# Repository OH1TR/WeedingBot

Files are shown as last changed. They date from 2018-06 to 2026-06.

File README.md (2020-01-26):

# This is collection of bits and pieces to build weeding bot. (or something)

Bot is build on frame of old lawn mover. Jetson Nano board handles communication with windows client. There is ZED-camera on board for images. Some custom PCB:s and China boards to contol motors.

Code is a mess, but it moves.. :-)

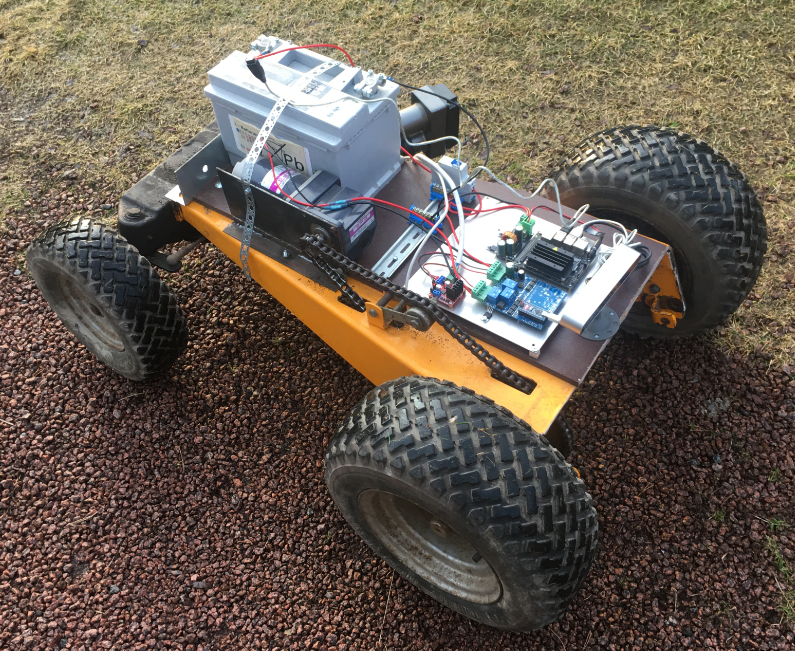
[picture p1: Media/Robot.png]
Robot


Video: https://www.facebook.com/100010379521880/videos/999905427032099/

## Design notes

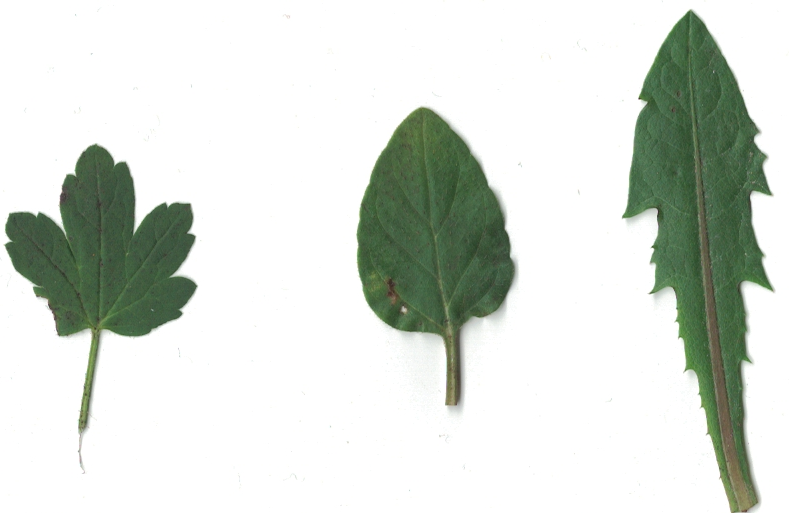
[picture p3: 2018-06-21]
RandomStuff/PlantDetect/Scanned.png

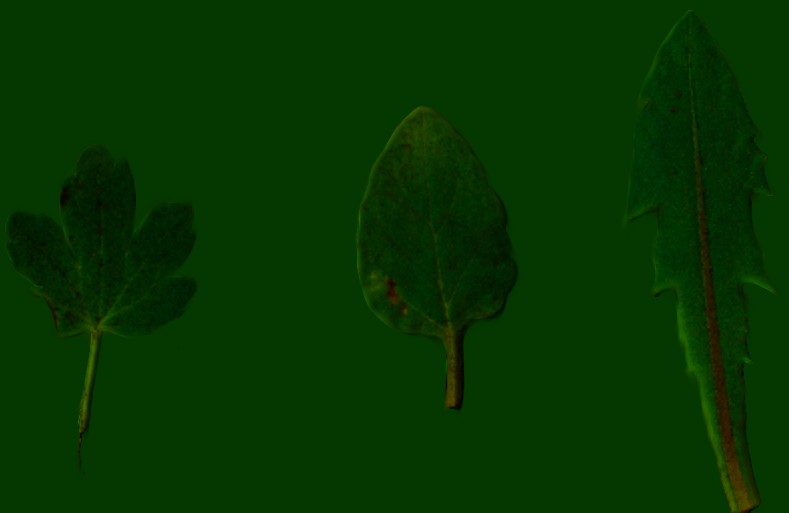
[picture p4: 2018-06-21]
RandomStuff/PlantDetect/Scanned2.png

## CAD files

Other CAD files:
RandomStuff/PlantDetect/pla.blend

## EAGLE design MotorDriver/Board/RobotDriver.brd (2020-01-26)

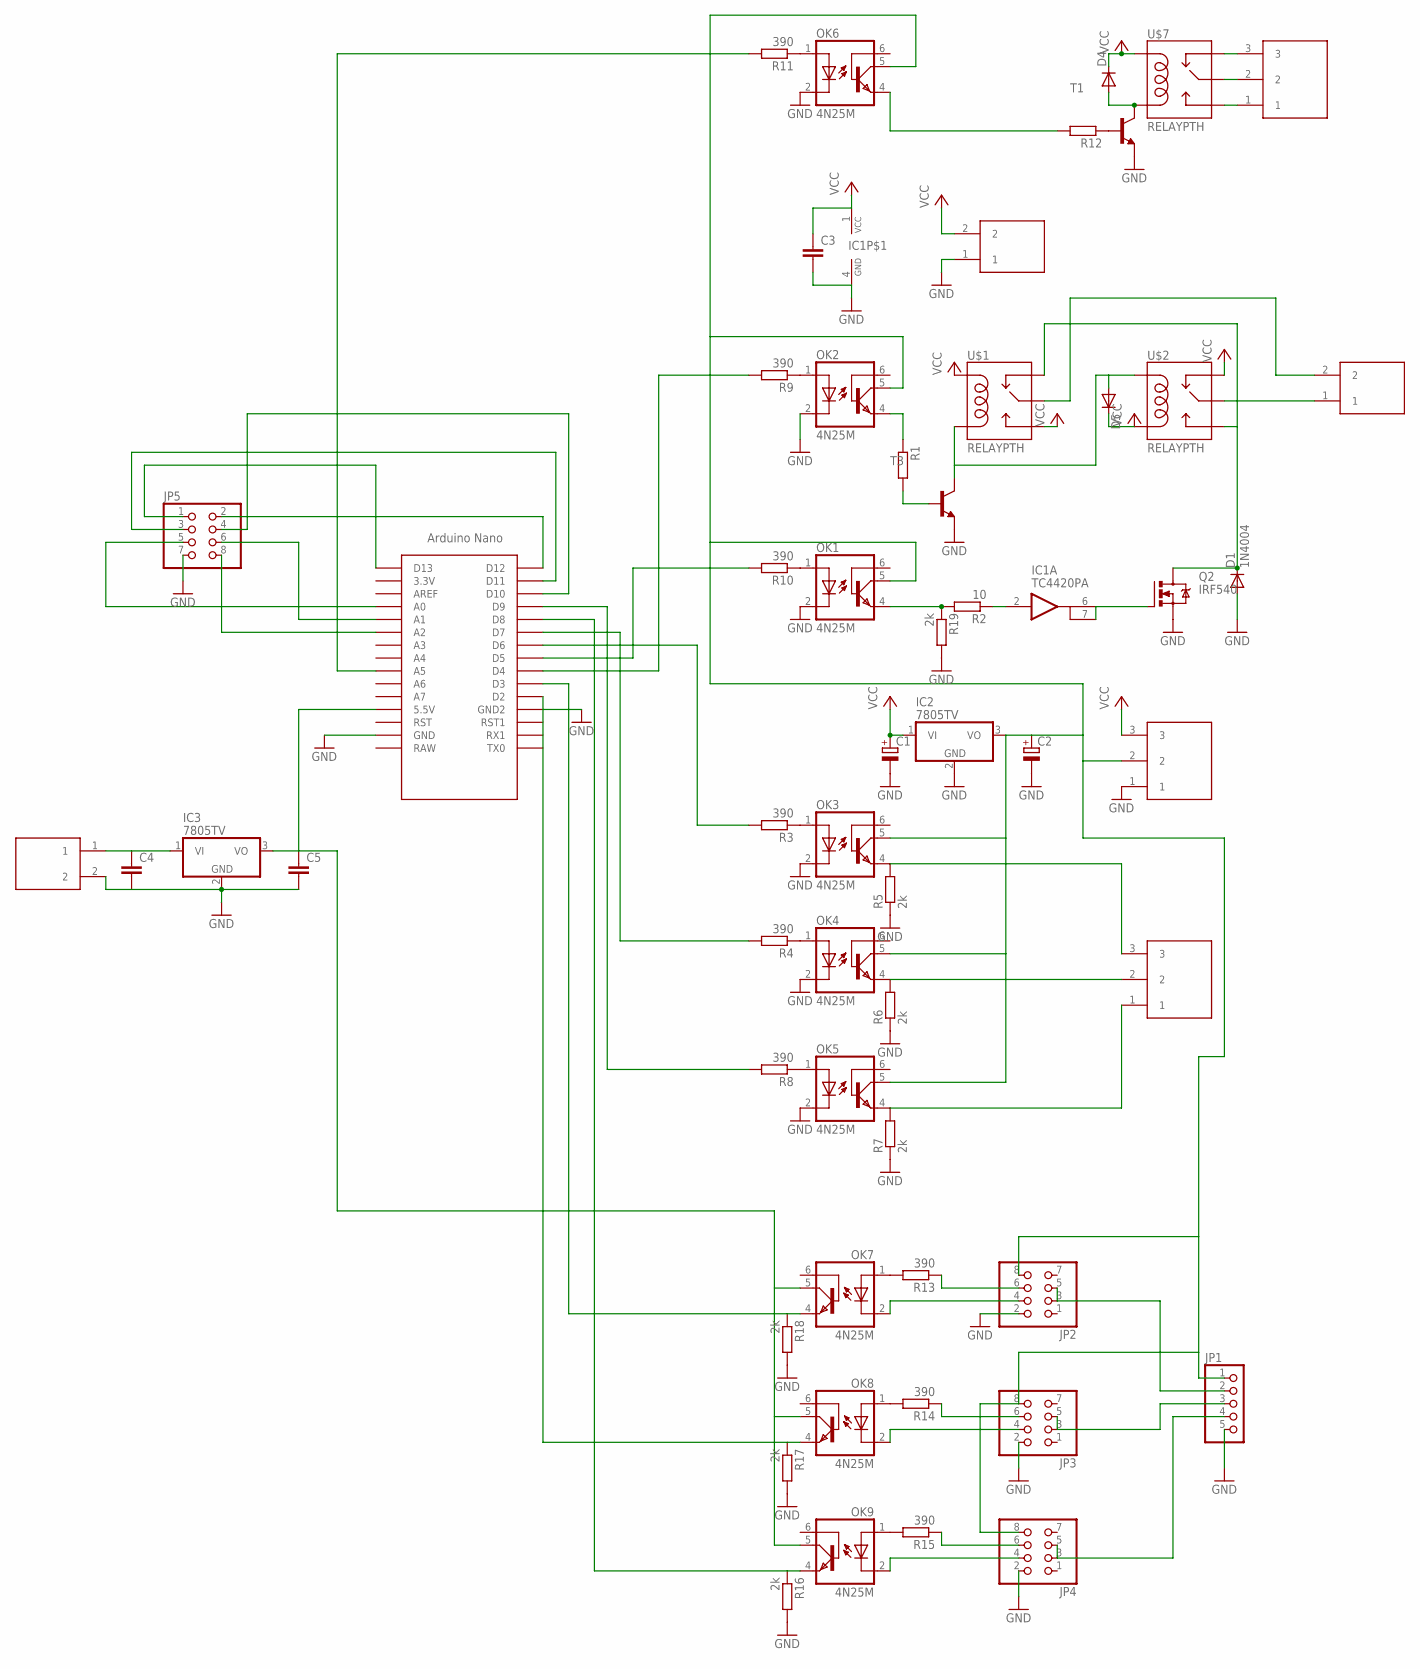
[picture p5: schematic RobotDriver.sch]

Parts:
C1, C2: CPOL-EUE5-10.5; E5-10,5
C3, C4, C5: C-EUC1206; C1206
D1: 1N4004; DO41-10
D4, D5: DIODE-DO214AA; DO214AA
IC1: TC4420PA; DIP08
IC2, IC3: 7805TV; TO220V
JP1: PINHD-1X5; 1X05
JP2, JP3, JP4, JP5: PINHD-2X4; 2X04
OK1, OK2, OK3, OK4, OK5, OK6, OK7, OK8, OK9: 4N25M; DIL06
Q2: IRF540; TO220BV
R1, R12: R-EU_R1210; R1210
R2: 10; R1210
R3, R4, R8, R9, R10, R11, R13, R14, R15: 390; R1210
R5, R6, R7, R16, R17, R18, R19: 2k; R1210
T1, T3: BC817-16-NPN-SOT23-BEC; SOT23-BEC
U$1, U$2, U$7: RELAYPTH; SRD-05VDC-SL-C
U$3: NANO
U$4, U$5, U$10: 2EDG-2; 2EGD-2-PAK
U$6, U$8, U$9: 2EDG-3; 2EGD-3-PAK

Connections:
GND: C1.-, C2.-, C3.2, C4.2, C5.2, D1.A, IC1.4 (GND), IC1.5 (GND), IC2.2 (GND), IC3.2 (GND), JP1.5, JP2.2, JP3.2, JP4.2, JP5.7, OK1.2 (C), OK2.2 (C), OK3.2 (C), OK4.2 (C), OK5.2 (C), OK6.2 (C), Q2.S, R5.1, R6.1, R7.1, R16.2, R17.2, R18.2, R19.2, T1.E, T3.E, U$3.GND, U$3.GND1 (GND2), U$5.1, U$9.1, U$10.2
unnamed: R1.2, T3.B
unnamed: D5.A, T3.C, U$1.COIL0, U$2.COIL1
unnamed: OK2.4 (EMI), R1.1
unnamed: D1.C, Q2.D, U$1.SWCLOSED (SWCLOSE), U$2.SWOPEN
unnamed: OK1.4 (EMI), R2.2, R19.1
unnamed: OK3.1 (A), R3.1
unnamed: OK2.1 (A), R9.1
unnamed: OK1.1 (A), R10.1
unnamed: R9.2, U$3.D4
unnamed: U$2.SWCOMMON, U$4.1
unnamed: U$1.SWCOMMON, U$4.2
unnamed: IC1.6 (OUT1), IC1.7 (OUT2), Q2.G
unnamed: C2.+, IC2.3 (VO), JP1.1, JP2.8, JP3.8, JP4.8, OK1.5 (COL), OK2.5 (COL), OK3.5 (COL), OK4.5 (COL), OK5.5 (COL), OK6.5 (COL), U$9.2
unnamed: OK3.4 (EMI), R5.2, U$6.3
unnamed: OK4.4 (EMI), R6.2, U$6.2
unnamed: OK5.4 (EMI), R7.2, U$6.1
unnamed: OK4.1 (A), R4.1
unnamed: OK5.1 (A), R8.1
unnamed: OK6.1 (A), R11.1
unnamed: D4.A, T1.C, U$7.COIL0
unnamed: R12.1, T1.B
unnamed: JP2.4, OK7.2 (C)
unnamed: OK6.4 (EMI), R12.2
unnamed: JP3.6, R14.1
unnamed: OK7.1 (A), R13.2
unnamed: OK8.1 (A), R14.2
unnamed: OK9.1 (A), R15.2
unnamed: JP3.4, OK8.2 (C)
unnamed: JP2.6, R13.1
unnamed: JP4.6, R15.1
unnamed: JP4.4, OK9.2 (C)
unnamed: IC1.2 (IN), R2.1
unnamed: C5.1, IC3.3 (VO), OK7.5 (COL), OK8.5 (COL), OK9.5 (COL), U$3.5V (5.5V)
unnamed: JP5.2, U$3.D12
unnamed: JP1.2, JP2.3, JP2.5
unnamed: JP1.3, JP3.3, JP3.5
unnamed: JP1.4, JP4.3, JP4.5
unnamed: OK9.4 (EMI), R16.1, U$3.D8
unnamed: OK8.4 (EMI), R17.1, U$3.D2
unnamed: OK7.4 (EMI), R18.1, U$3.D3
unnamed: U$7.SWCLOSED (SWCLOSE), U$8.3
unnamed: U$7.SWCOMMON, U$8.2
unnamed: U$7.SWOPEN, U$8.1
unnamed: C4.1, IC3.1 (VI), U$10.1
unnamed: R11.2, U$3.A5
unnamed: JP5.1, U$3.D13
unnamed: R10.2, U$3.D5
unnamed: R3.2, U$3.D6
unnamed: R4.2, U$3.D7
unnamed: R8.2, U$3.D9
unnamed: JP5.3, U$3.D11
unnamed: JP5.4, U$3.D10
unnamed: JP5.5, U$3.A0
unnamed: JP5.6, U$3.A1
unnamed: JP5.8, U$3.A2
VCC: C1.+, C3.1, D4.C, D5.C, IC1.1 (VCC), IC1.8 (VCC), IC2.1 (VI), U$1.COIL1, U$1.SWOPEN, U$2.COIL0, U$2.SWCLOSED (SWCLOSE), U$5.2, U$7.COIL1, U$9.3

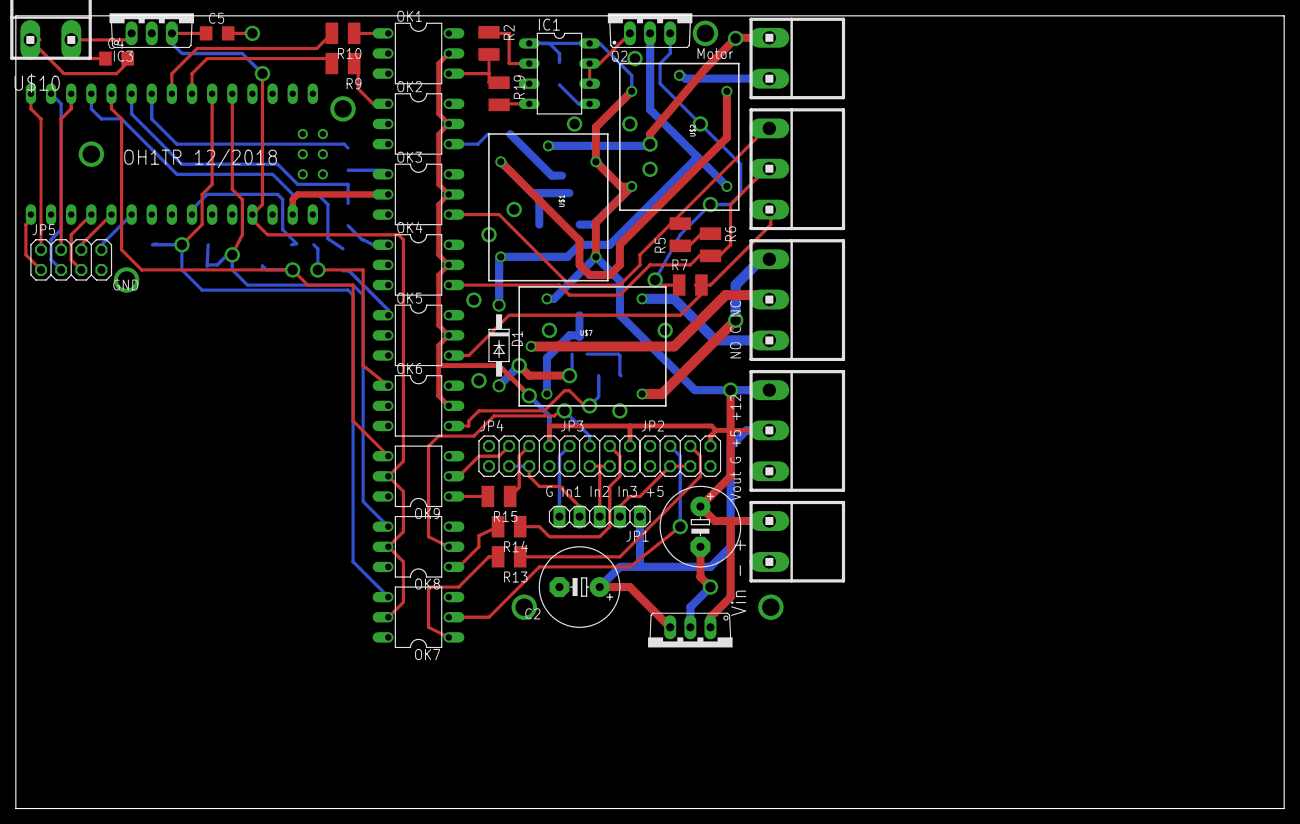
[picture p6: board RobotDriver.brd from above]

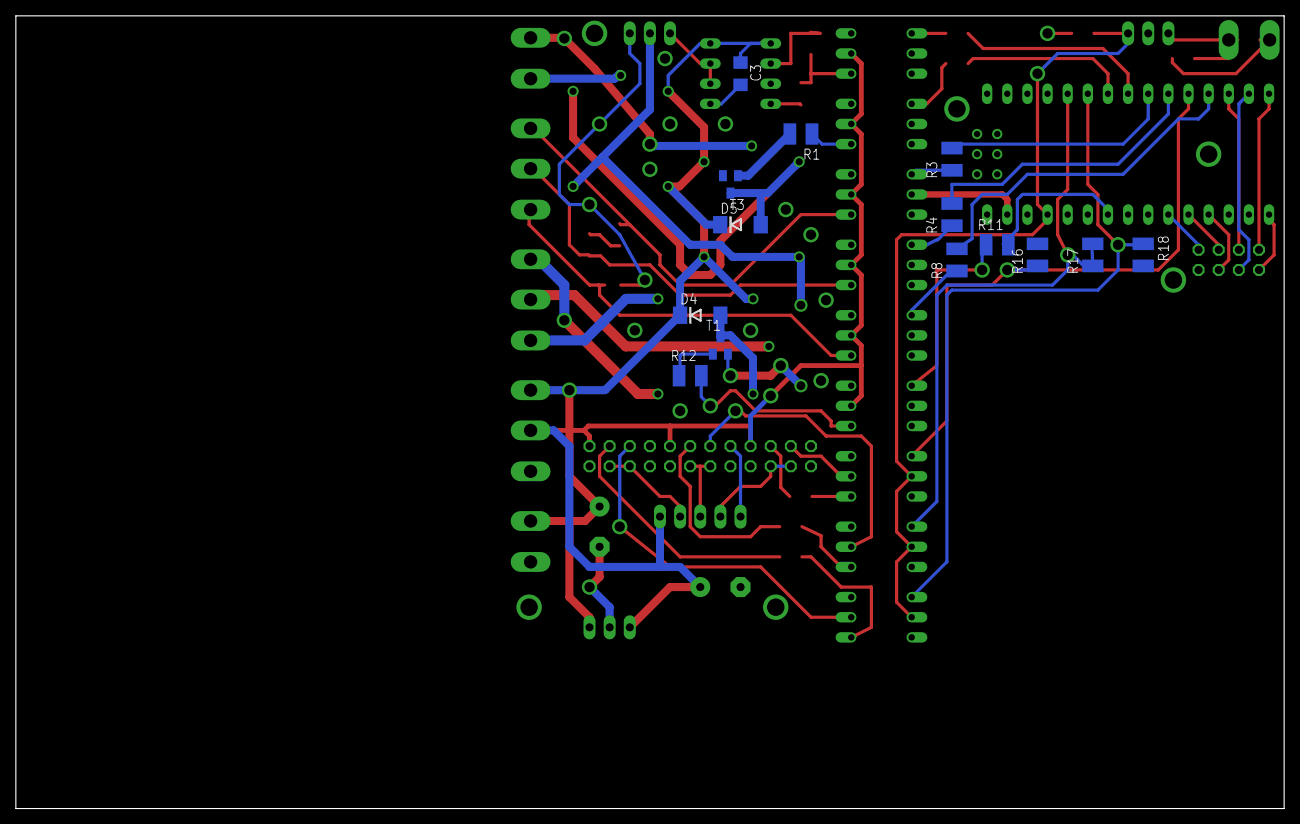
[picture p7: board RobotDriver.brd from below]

Board: 2 copper layers, 160.0 x 100.0 mm, 57 parts (14 on the bottom side), 57 nets.

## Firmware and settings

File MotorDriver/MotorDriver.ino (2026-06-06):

/*
  PWM motor control
 */

// PWM out pin
const int PwmPin = 5;

// Direction select pin, controls relays
const int DirectionPin=4;


const int L298In1Pin=6;
const int L298In2Pin=7;

const int OptoIn2Pin=2;
const int OptoIn3Pin=3;

// Stop motor if no command byte in 100ms*CounterReset
const int CounterReset=50;

// Data from serial port. MSB byte selects direction, 7 LSB PWM value
int InByte = 50;

// Conter for stopping motor if no command bytes seen lately.
long Counter=0;

int targetPosition=0;
int position=0;

void setup() {
  pinMode(DirectionPin, OUTPUT);
  
  pinMode(L298In1Pin, OUTPUT);
  pinMode(L298In2Pin, OUTPUT);
  
  pinMode(OptoIn2Pin, INPUT);
  pinMode(OptoIn3Pin, INPUT);

  attachInterrupt(digitalPinToInterrupt(OptoIn2Pin), &OptoISR, CHANGE);
  attachInterrupt(digitalPinToInterrupt(OptoIn3Pin), &OptoISR2, CHANGE);
  
  Serial.begin(1200);
}

void OptoISR() {
     if(digitalRead(OptoIn2Pin)==HIGH)
    {
      if(digitalRead(OptoIn3Pin)==HIGH)
        position--;
      else
        position++;
    }
  else
  {
      if(digitalRead(OptoIn3Pin)==HIGH)
        position++;
      else
        position--;
  }
}

void OptoISR2() {
  if(digitalRead(OptoIn3Pin)==HIGH)
    {
      if(digitalRead(OptoIn2Pin)==HIGH)
        position++;
      else
        position--;
    }
  else
  {
      if(digitalRead(OptoIn2Pin)==HIGH)
        position--;
      else
        position++;
  }
}


char cmdBuf[50];
int cmdBufPos=0;

int ParseInt(char *buf)
{
    int d=buf[0]=='-' ? -1 : 1;
    int s=buf[1]-'0';
    int k=buf[2]-'0';
    int y=buf[3]-'0';
    return((s*100+k*10+y)*d);
}

void processCommand(char *cmd)
{
  // Zero steering position
  if(cmd[0]=='Z')
  {
    noInterrupts();
    position=0;
    targetPosition=0;
    interrupts();
    Counter=0;
  }

  // Set steering target value
  if(cmd[0]=='S')
  {
    noInterrupts();
    targetPosition = - ParseInt(cmd+1);
    interrupts();
    Counter=0;
  }

  // Set Drive motor direction and speed
  if(cmd[0]=='W')
  {
    
    int targetDrive = ParseInt(cmd+1);
    if(targetDrive>=0)
    {
      digitalWrite(DirectionPin,LOW);
      delay(50);
      analogWrite(PwmPin,targetDrive);
    }
    else
    {
      if(targetDrive!=0)
        digitalWrite(DirectionPin,HIGH);
      
      delay(50);
      analogWrite(PwmPin,-targetDrive);
    }
    Counter=0;
  }

  if(cmd[0]=='D')
  {
    Serial.print("targetPosition=");
    Serial.print(targetPosition);
    Serial.print(" Position=");
    Serial.print(position);
    Serial.print("\n");
    Counter=0;
  }
}

void loop() 
{
  if (Serial.available() > 0)
  {
    Counter=0;
    
    byte inByte = Serial.read();
    
    if(inByte=='w')
    {
      digitalWrite(DirectionPin,HIGH);
      delay(50);
      analogWrite(PwmPin,255);
      Counter=0;
      return;
    } 

    if(inByte=='s')
    {
      digitalWrite(DirectionPin,LOW);
      delay(50);
      analogWrite(PwmPin,255);
      Counter=0;
      return;
    } 

    if(inByte=='a')
    {
     targetPosition=-999;
     Counter=0;
     return;
    }     

    if(inByte=='d')
    {
     targetPosition=999;
     Counter=0;
     return;
    }     
    
    cmdBuf[cmdBufPos]=inByte;
    cmdBufPos++;

    if(inByte==13)
    {
      cmdBuf[cmdBufPos-1]=0;
      processCommand(cmdBuf);
      cmdBufPos=0;
    }
  }
  
  if(targetPosition>position)
  {   
    digitalWrite(L298In1Pin,LOW);
    digitalWrite(L298In2Pin,HIGH);
  }
  else if(targetPosition<position)
  {
    digitalWrite(L298In1Pin,HIGH);
    digitalWrite(L298In2Pin,LOW);
  }
  else if(targetPosition==position)
  {
    digitalWrite(L298In1Pin,LOW);
    digitalWrite(L298In2Pin,LOW); 
  }
  Counter++;
  if(Counter>100000)
  {
    digitalWrite(L298In1Pin,LOW);
    digitalWrite(L298In2Pin,LOW);
    targetPosition=position;
    analogWrite(PwmPin,0);
    Serial.print("All stop\n");
    Counter=0;
  }  
}  

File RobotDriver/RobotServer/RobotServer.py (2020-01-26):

import socketserver
from protocol_pb2 import Steering,Image
from google.protobuf.any_pb2 import Any
from threading import Lock,Thread
import time
import cv2
import array
from numproto import ndarray_to_proto, proto_to_ndarray
import traceback
import serial

global connectedSocket, connectedSocketLock, ser

connectedSocket=None
connectedSocketLock = Lock()

class MyTCPHandler(socketserver.BaseRequestHandler):

    def handle(self):
        global connectedSocket, connectedSocketLock

        connectedSocketLock.acquire()
        try:
            connectedSocket=self.request
        finally:
            connectedSocketLock.release()

        while(1):
            try:
                print("R")
                lenBytes=self.request.recv(4)

                if not lenBytes:
                    break

                len = int.from_bytes(bytearray(lenBytes), byteorder='little', signed=False)
                data = self.request.recv(len)

                if not data:
                    break
                print("P")
                o=Steering()
                o.ParseFromString(data)
                values = bytearray(o.command,'ascii')
                ser.write(values)
                print(o.command)
            except:
                print("R Exception")
                print(traceback.format_exc())
                break;
        self.request.close()
        print("Q1")
        connectedSocketLock.acquire()
        try:
            connectedSocket=None
        finally:
            connectedSocketLock.release()
        print("Q2")

def startServer():
    with socketserver.TCPServer((HOST, PORT), MyTCPHandler) as server:
        server.serve_forever()




if __name__ == "__main__":
    ser = serial.Serial('/dev/ttyUSB0',1200,rtscts=0)
    HOST, PORT = "your ip", 9997
    t=Thread(target=startServer)
    t.start()
    cap = cv2.VideoCapture(0)
    cap.set(cv2.CAP_PROP_FRAME_WIDTH, 2560)
    cap.set(cv2.CAP_PROP_FRAME_HEIGHT, 720)

    while(1):
        connectedSocketLock.acquire()
        try:
            if(connectedSocket!=None):
                try:
                    for i in range(3):
                        cap.read()
                    ret, img = cap.read()
                    #retval=array.array('i',cv2.imencode(".png",img)[1])

                    x=Image()
                    x.format="jpg"
                    x.data=cv2.imencode(".jpg",img[:,0:1024])[1].tobytes()
                    msg=x.SerializeToString()
                    lmsg=len(msg).to_bytes(4, byteorder='little')
                    connectedSocket.send(lmsg)
                    connectedSocket.send(msg)
                    print('.')
                except:
                        print("Send Exception")
                        print(traceback.format_exc())
                        connectedSocket=None
        finally:
            connectedSocketLock.release()

        #time.sleep(10)

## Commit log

2017-12-09 Initial commit.
    [MotorDriver.brd, MotorDriver.sch]
2020-01-26 Test run done!
    [MotorDriver.brd, MotorDriver.sch, RobotDriver.brd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]
2026-06-05 Update MotorDriver.ino
    wasd drive.
2026-06-06 Update MotorDriver.ino
    .
